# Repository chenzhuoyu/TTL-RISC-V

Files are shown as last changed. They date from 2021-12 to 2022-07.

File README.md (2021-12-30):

# TTL RISC-V

RISC-V processor & peripherals made (almost) entirely with 74-series TTL logic chips.

This repository contains the KiCAD schematics and PCB drawings of the processor, along with the related software source code.

This is designed to be as simple as possible, but it should be a practical processor rather than a pure-educational one.

## Current Design Goals

* Implements the `RV32IMZicsr_Zifencei` instruction set.
* Runs at least `8MHz` clock speed.
* 2-stage pipelines.
* Interrupts.
* Mostly single clock cycle instructions.
* Supports the 6800 bus interface (e.g. R/W and STROBE signals).
* Bus arbitration to support external DMA controllers or co-processors.

## Future Design Goals (maybe)

* Higher clock speed?
* Deeper pipelines?
* Out-of-order?
* Superscalar? It might require too many chips to implement :(

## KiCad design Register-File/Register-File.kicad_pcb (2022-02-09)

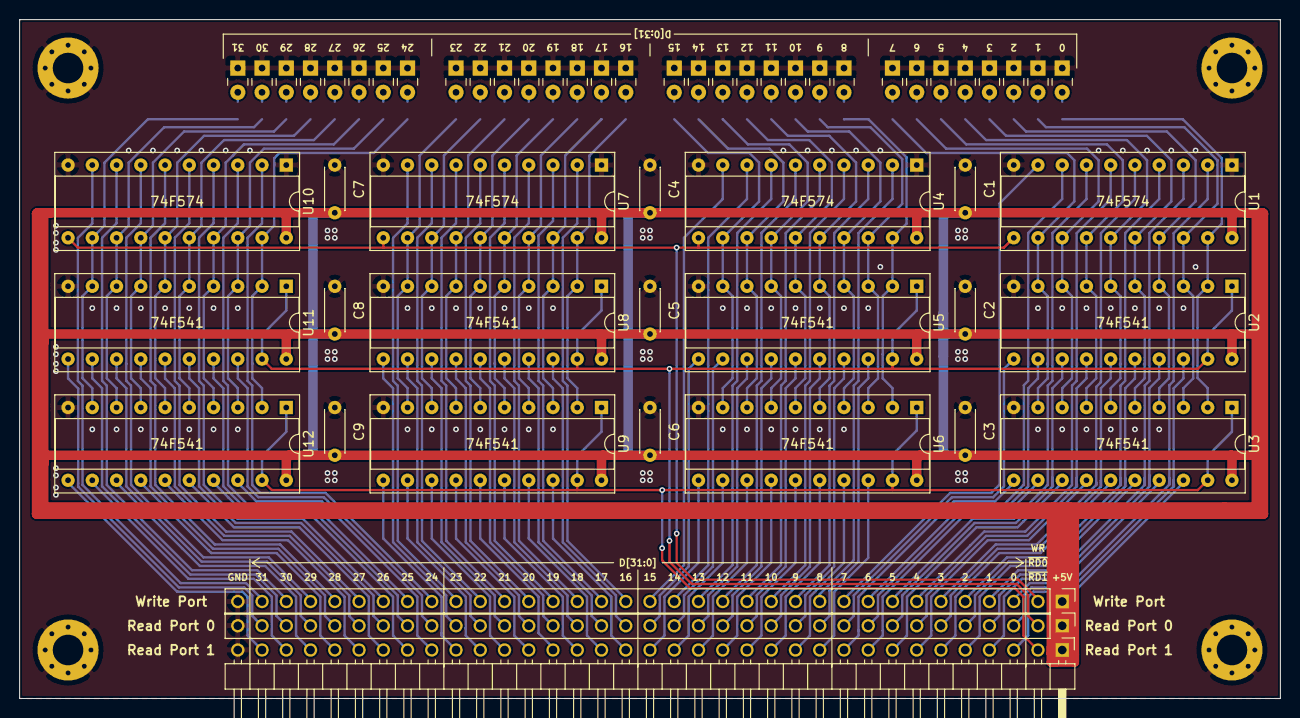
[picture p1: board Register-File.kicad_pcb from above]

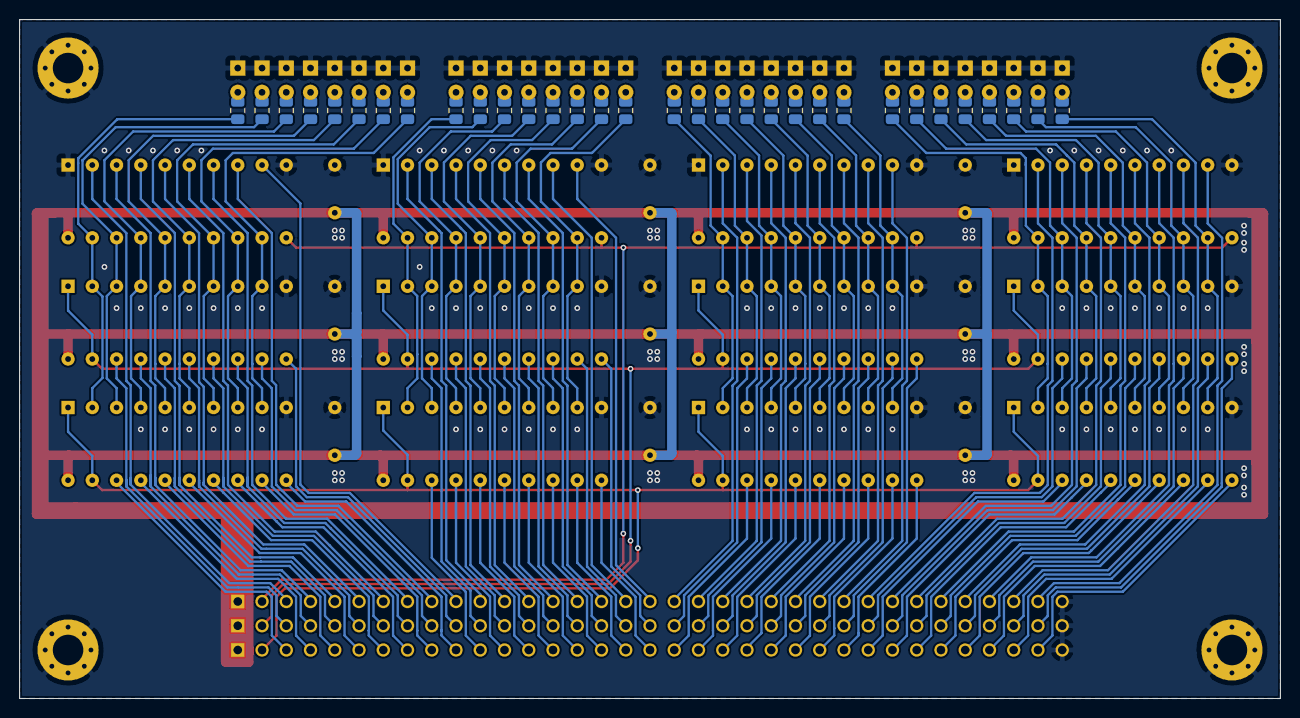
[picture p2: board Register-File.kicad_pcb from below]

Board: 2 copper layers, 132.1 x 71.1 mm, 92 parts (32 on the bottom side), 165 nets.

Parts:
C1, C2, C3, C4, C5, C6, C7, C8, C9: C_Small; C_Disc_D4.3mm_W1.9mm_P5.00mm
D1, D2, D3, D4, D5, D6, D7, D8, D9, D10, D11, D12, D13, D14, D15, D16, D17, D18, D19, D20, D21, D22, D23, D24, D25, D26, D27, D28, D29, D30, D31, D32: LED_Small; LED_Rectangular_W3.0mm_H2.0mm
H1, H2, H3, H4: MountingHole_Pad; MountingHole_3.2mm_M3_Pad_Via
J1, J2: Conn_01x35_Male; PinHeader_1x35_P2.54mm_Vertical
J3: Conn_01x35_Male; PinHeader_1x35_P2.54mm_Horizontal
R1, R2, R3, R4, R5, R6, R7, R8, R9, R10, R11, R12, R13, R14, R15, R16, R17, R18, R19, R20, R21, R22, R23, R24, R25, R26, R27, R28, R29, R30, R31, R32: R_Small; R_0805_2012Metric
U1, U4, U7, U10: 74LS574; DIP-20_W7.62mm_Socket
U2, U3, U5, U6, U8, U9, U11, U12: 74LS541; DIP-20_W7.62mm_Socket

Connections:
+5V: C1.1, C2.1, C3.1, C4.1, C5.1, C6.1, C7.1, C8.1, C9.1, J1.1, J2.1, J3.1, U1.20, U2.20, U3.20, U4.20, U5.20, U6.20, U7.20, U8.20, U9.20, U10.20, U11.20, U12.20
/D0: R1.1, U1.19, U2.2, U3.2
/D1: R2.1, U1.18, U2.3, U3.3
/D2: R3.1, U1.17, U2.4, U3.4
/D3: R4.1, U1.16, U2.5, U3.5
/D4: R5.1, U1.15, U2.6, U3.6
/D5: R6.1, U1.14, U2.7, U3.7
/D6: R7.1, U1.13, U2.8, U3.8
/D7: R8.1, U1.12, U2.9, U3.9
/D8: R9.1, U4.19, U5.2, U6.2
/D9: R10.1, U4.18, U5.3, U6.3
/D10: R11.1, U4.17, U5.4, U6.4
/D11: R12.1, U4.16, U5.5, U6.5
/D12: R13.1, U4.15, U5.6, U6.6
/D13: R14.1, U4.14, U5.7, U6.7
/D14: R15.1, U4.13, U5.8, U6.8
/D15: R16.1, U4.12, U5.9, U6.9
/D16: R17.1, U7.19, U8.2, U9.2
/D17: R18.1, U7.18, U8.3, U9.3
/D18: R19.1, U7.17, U8.4, U9.4
/D19: R20.1, U7.16, U8.5, U9.5
/D20: R21.1, U7.15, U8.6, U9.6
/D21: R22.1, U7.14, U8.7, U9.7
/D22: R23.1, U7.13, U8.8, U9.8
/D23: R24.1, U7.12, U8.9, U9.9
/D24: R25.1, U10.19, U11.2, U12.2
/D25: R26.1, U10.18, U11.3, U12.3
/D26: R27.1, U10.17, U11.4, U12.4
/D27: R28.1, U10.16, U11.5, U12.5
/D28: R29.1, U10.15, U11.6, U12.6
/D29: R30.1, U10.14, U11.7, U12.7
/D30: R31.1, U10.13, U11.8, U12.8
/D31: R32.1, U10.12, U11.9, U12.9
/RD0: J2.2, U2.1, U2.19, U5.1, U5.19, U8.1, U8.19, U11.1, U11.19
/RD1: J3.2, U3.1, U3.19, U6.1, U6.19, U9.1, U9.19, U12.1, U12.19
/WD0: J1.3, U1.2
/WD1: J1.4, U1.3
/WD2: J1.5, U1.4
/WD3: J1.6, U1.5
/WD4: J1.7, U1.6
/WD5: J1.8, U1.7
/WD6: J1.9, U1.8
/WD7: J1.10, U1.9
/WD8: J1.11, U4.2
/WD9: J1.12, U4.3
/WD10: J1.13, U4.4
/WD11: J1.14, U4.5
/WD12: J1.15, U4.6
/WD13: J1.16, U4.7
/WD14: J1.17, U4.8
/WD15: J1.18, U4.9
/WD16: J1.19, U7.2
/WD17: J1.20, U7.3
/WD18: J1.21, U7.4
/WD19: J1.22, U7.5
/WD20: J1.23, U7.6
/WD21: J1.24, U7.7
/WD22: J1.25, U7.8
/WD23: J1.26, U7.9
/WD24: J1.27, U10.2
/WD25: J1.28, U10.3
/WD26: J1.29, U10.4
/WD27: J1.30, U10.5
/WD28: J1.31, U10.6
/WD29: J1.32, U10.7
/WD30: J1.33, U10.8
/WD31: J1.34, U10.9
/WR: J1.2, U1.11, U4.11, U7.11, U10.11
/X0: J2.3, U2.18
/X1: J2.4, U2.17
/X2: J2.5, U2.16
/X3: J2.6, U2.15
/X4: J2.7, U2.14
/X5: J2.8, U2.13
/X6: J2.9, U2.12
/X7: J2.10, U2.11
/X8: J2.11, U5.18
/X9: J2.12, U5.17
/X10: J2.13, U5.16
/X11: J2.14, U5.15
/X12: J2.15, U5.14
/X13: J2.16, U5.13
/X14: J2.17, U5.12
/X15: J2.18, U5.11
/X16: J2.19, U8.18
/X17: J2.20, U8.17
/X18: J2.21, U8.16
/X19: J2.22, U8.15
/X20: J2.23, U8.14
/X21: J2.24, U8.13
/X22: J2.25, U8.12
/X23: J2.26, U8.11
/X24: J2.27, U11.18
/X25: J2.28, U11.17
/X26: J2.29, U11.16
/X27: J2.30, U11.15
/X28: J2.31, U11.14
/X29: J2.32, U11.13
/X30: J2.33, U11.12
/X31: J2.34, U11.11
/Y0: J3.3, U3.18
/Y1: J3.4, U3.17
/Y2: J3.5, U3.16
/Y3: J3.6, U3.15
/Y4: J3.7, U3.14
/Y5: J3.8, U3.13
/Y6: J3.9, U3.12
/Y7: J3.10, U3.11
/Y8: J3.11, U6.18
/Y9: J3.12, U6.17
/Y10: J3.13, U6.16
/Y11: J3.14, U6.15
/Y12: J3.15, U6.14
/Y13: J3.16, U6.13
/Y14: J3.17, U6.12
/Y15: J3.18, U6.11
/Y16: J3.19, U9.18
/Y17: J3.20, U9.17
/Y18: J3.21, U9.16
/Y19: J3.22, U9.15
/Y20: J3.23, U9.14
/Y21: J3.24, U9.13
/Y22: J3.25, U9.12
/Y23: J3.26, U9.11
/Y24: J3.27, U12.18
/Y25: J3.28, U12.17
/Y26: J3.29, U12.16
/Y27: J3.30, U12.15
/Y28: J3.31, U12.14
/Y29: J3.32, U12.13
/Y30: J3.33, U12.12
/Y31: J3.34, U12.11
GND: C1.2, C2.2, C3.2, C4.2, C5.2, C6.2, C7.2, C8.2, C9.2, D1.1, D2.1, D3.1, D4.1, D5.1, D6.1, D7.1, D8.1, D9.1, D10.1, D11.1, D12.1, D13.1, D14.1, D15.1, D16.1, D17.1, D18.1, D19.1, D20.1, D21.1, D22.1, D23.1, D24.1, D25.1, D26.1, D27.1, D28.1, D29.1, D30.1, D31.1, D32.1, H1.1, H2.1, H3.1, H4.1, J1.35, J2.35, J3.35, U1.1, U1.10, U2.10, U3.10, U4.1, U4.10, U5.10, U6.10, U7.1, U7.10, U8.10, U9.10, U10.1, U10.10, U11.10, U12.10
unnamed: D1.2, R1.2
unnamed: D2.2, R2.2
unnamed: D3.2, R3.2
unnamed: D4.2, R4.2
unnamed: D5.2, R5.2
unnamed: D6.2, R6.2
unnamed: D7.2, R7.2
unnamed: D8.2, R8.2
unnamed: D9.2, R9.2
unnamed: D10.2, R10.2
unnamed: D11.2, R11.2
unnamed: D12.2, R12.2
unnamed: D13.2, R13.2
unnamed: D14.2, R14.2
unnamed: D15.2, R15.2
unnamed: D16.2, R16.2
unnamed: D17.2, R17.2
unnamed: D18.2, R18.2
unnamed: D19.2, R19.2
unnamed: D20.2, R20.2
unnamed: D21.2, R21.2
unnamed: D22.2, R22.2
unnamed: D23.2, R23.2
unnamed: D24.2, R24.2
unnamed: D25.2, R25.2
unnamed: D26.2, R26.2
unnamed: D27.2, R27.2
unnamed: D28.2, R28.2
unnamed: D29.2, R29.2
unnamed: D30.2, R30.2
unnamed: D31.2, R31.2
unnamed: D32.2, R32.2

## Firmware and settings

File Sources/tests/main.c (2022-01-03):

#include <stdint.h>

#define IOV_BASE    ((volatile char *)(0xc0000000))
#define IOV_DISPLAY (IOV_BASE + 0x8000)

#define DISPLAY     (*(volatile uint32_t *)IOV_DISPLAY)

#define ECALL       0x0000000b
#define EXTINT      0x8000000b

#define MIE         (1 << 3)
#define MEIE        (1 << 11)

#define SYS_DISPLAY 1

void display(uint32_t val) {
    asm volatile (
        "li a0, 1\n"
        "mv a1, %0\n"
        "ecall\n"
        :: "r"(val)
    );
}

void main() {
    uint32_t a;
    uint32_t b;
    uint32_t c;
    for (;;) {
        a = 1;
        b = 1;
        display(a);
        display(b);
        while (!__builtin_uaddl_overflow(a, b, &c)) {
            display(c);
            a = b;
            b = c;
        }
    }
}

/** Interrupt & ECALL Handling **/

typedef struct _frame_t {
    uint32_t pc;
    uint32_t ra;
    uint32_t sp;
    uint32_t gp;
    uint32_t tp;
    uint32_t t0;
    uint32_t t1;
    uint32_t t2;
    uint32_t fp;
    uint32_t s1;
    uint32_t a0;
    uint32_t a1;
    uint32_t a2;
    uint32_t a3;
    uint32_t a4;
    uint32_t a5;
    uint32_t a6;
    uint32_t a7;
    uint32_t s2;
    uint32_t s3;
    uint32_t s4;
    uint32_t s5;
    uint32_t s6;
    uint32_t s7;
    uint32_t s8;
    uint32_t s9;
    uint32_t s10;
    uint32_t s11;
    uint32_t t3;
    uint32_t t4;
    uint32_t t5;
    uint32_t t6;
} frame_t;

void sys_display(uint32_t val) {
    DISPLAY = val;
}

void isr_syscall(frame_t *frame) {
    switch (frame->a0) {
        case SYS_DISPLAY: sys_display(frame->a1); break;
    }
}

void isr_handler(frame_t *frame, uint32_t cause) {
    switch (cause) {
        case ECALL  : isr_syscall(frame); frame->pc += 4; break;
        case EXTINT : DISPLAY = 99999999; break;
    }
}

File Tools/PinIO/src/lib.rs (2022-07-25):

use std::pin::Pin;

use bitvec::BitArr;
use ftd2xx_embedded_hal::{
    embedded_hal::{
        digital::v2::OutputPin as OutputPinTrait, prelude::_embedded_hal_blocking_spi_Transfer,
    },
    libftd2xx::{Ft2232h, MpsseSettings},
    Ft2232hHal, Initialized, OutputPin, Spi,
};
use ouroboros::self_referencing;

pub type Unit = Maybe<()>;
pub type Error = Box<dyn std::error::Error + Sync + Send>;
pub type Maybe<T> = Result<T, Error>;

#[inline]
pub fn as_err<T: std::error::Error + Sync + Send + 'static>(e: T) -> Error {
    Box::new(e) as Error
}

#[self_referencing]
struct PinIoInternal {
    hal: Ft2232hHal<Initialized>,
    #[borrows(hal)]
    #[covariant]
    spi: Spi<'this, Ft2232h>,
    #[borrows(hal)]
    #[covariant]
    sel: OutputPin<'this, Ft2232h>,
}

pub type PinState = BitArr!(for 64, in u8);

pub struct PinIo {
    m: Pin<Box<PinIoInternal>>,
}

impl PinIo {
    pub fn new() -> Maybe<Self> {
        Ok(Self {
            m: Box::pin(
                PinIoInternalTryBuilder {
                    hal: Ft2232hHal::new()?.init(&MpsseSettings {
                        clock_frequency: Some(30_000_000),
                        ..Default::default()
                    })?,
                    spi_builder: |hal| hal.spi(),
                    sel_builder: |hal| Ok(hal.ad3()),
                }
                .try_build()?,
            ),
        })
    }
}

impl PinIo {
    pub fn transfer(&mut self, v: &PinState) -> Maybe<PinState> {
        let mut m = v.clone();
        self.m.with_sel_mut(|s| s.set_low())?;
        self.m.with_spi_mut(|s| s.transfer(m.as_raw_mut_slice()))?;
        self.m.with_sel_mut(|s| s.set_high())?;
        Ok(m)
    }
}

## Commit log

2021-09-01 feat: register bank layer 0
    [Layer0.sch]
2021-09-01 feat: add silk screen printing
2021-09-18 feat: redesign the register file
    [Layer0.sch, Register-File.kicad_pcb, Register-File.sch]
2021-09-19 fix: fix ground filling
    [Register-File.kicad_pcb]
2021-09-23 fix: fix LED markings
    [Register-File.kicad_pcb]
2021-09-26 fix: enlarge pads for pin header
    [Register-File.kicad_pcb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]
2021-09-28 feat: immediate decoder circuit & GAL functions
2021-10-15 feat: boolean logic synthesis tool
    [Register-File.kicad_pcb]
2021-11-02 wip: half-working prototype
2021-11-20 chore: circuit cleanup
2021-12-04 chore: about to construct the interrupt handler
2021-12-07 wip: half-finished interrupt controller
2021-12-30 fix: fix immediate decoding
    [main.c]
2022-01-01 chore: save schematics
2022-01-03 fix: fix handling of external interrupts
    [main.c]
2022-01-03 feat: optimize interrupt controller
2022-01-03 feat: optimize circuit
2022-01-10 opt: use PLA for interrupt controller
2022-02-09 feat: simplify instruction decoder
    [Register-File.kicad_pcb]
2022-07-09 chore: update schematics & things
2022-07-09 feat: working divider circuit
2022-07-25 feat: add PinIO tool
    [Register-File.kicad_sch, Register-File.sch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]
